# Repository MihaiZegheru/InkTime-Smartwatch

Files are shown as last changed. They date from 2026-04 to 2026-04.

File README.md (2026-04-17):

# InkTime Watch

Low-power open-source smartwatch hardware based on the **nRF52840**, designed around a **1.54” sunlight-readable e-paper display**, **BLE notifications**, **step counting**, **USB charging**, and a reliable **SWD recovery path**.

---

## Overview

InkTime is a time-first smartwatch optimized for:
- **low average power consumption**
- **high outdoor readability**
- **simple glanceable UI**
- **robust programming and recovery**
- **practical assembly for EVT/DVT prototypes**

### MVP features
- 1.54” e-paper display, **200 × 200 px**
- Partial display refresh **once per minute** for the watch face
- **BLE** notifications from a phone, with haptic alerts
- Always-on **step counting** using the accelerometer’s embedded pedometer
- **USB-C charging**
- **Tag-Connect TC2030** SWD programming/debug access

---

## Block Diagram

```text
USB-C 5V (VBUS)
   |
   v
+-------------------+
| BQ25180 Charger   |
| IN, BAT, SYS,I2C  |
+----+---------+----+
     |         |
   VBAT       VSYS
     |         |
     |         v
     |   +-------------------+
     |   | RT6160 Buck-Boost |
     |   | VIN -> 3V3        |
     |   +---------+---------+
     |             |
     v             v
+-----------+   +-------------------------------+
| MAX17048  |   | nRF52840                      |
| FuelGauge |   | BLE, USB, SPI, I2C, GPIO,SWD |
+-----+-----+   +--+---------+---------+--------+
      |            |         |         |
      |            |         |         |
      |            |         |         +--> Buttons x3
      |            |         |
      |            |         +------------> DRV2605L + ERM motor
      |            |
      |            +----------------------> BMA421 accelerometer
      |
      +-----------------------------------> Battery status / alerts

nRF52840 SPI + GPIO
        |
        v
+-------------------+
| PFET power switch |
| controls VEPD     |
+---------+---------+
          |
          v
+-------------------+
| 1.54" E-paper     |
| 200x200 display   |
+-------------------+

Tag-Connect TC2030 -> SWDIO / SWDCLK / nRESET / 3V3 / GND
```

---

## Repository Structure

```text
Hardware/
├── Schematic.sch
├── PCB.brd
└── Schematic.pdf

Manufacturing/
├── gerbers.zip
├── Bill_of_Materials.bom
└── Pick_and_Place.cpl

Mechanical/
├── InkTime-Model-Exploded.step
└── InkTime-Model.f3z

Images/
├── Exploaded.png
├── PCB.png
└── Watch.png

LICENSE
README.md
```

---

## Bill of Materials

> Main BOM items only. Passives, crystals, RF matching parts, and decoupling capacitors are listed in the exported manufacturing BOM.

| Qty | Function | Part | Ref. | JLC / LCSC | Datasheet |
|---:|---|---|---|---|---|
| 1 | MCU | nRF52840-QIAA-R | U1 | [C190794](https://jlcpcb.com/partdetail/NordicSemicon-NRF52840_QIAAR/C190794) | [Nordic Product Spec](https://docs.nordicsemi.com/bundle/ps_nrf52840/page/keyfeatures_html5.html) |
| 1 | Charger / power path | BQ25180YBGR | IC1 | [TI part page](https://www.ti.com/product/BQ25180/part-details/BQ25180YBGR) | [BQ25180 datasheet](https://www.ti.com/lit/gpn/BQ25180) |
| 1 | 3.3V regulator | RT6160AWSC | IC9 | [C7065276](https://www.lcsc.com/product-detail/C7065276.html) | [Richtek datasheet](https://www.richtek.com/Assets/product_file/RT6160A=RT6160B/DS6160AB-04.pdf) |
| 1 | Fuel gauge | MAX17048G+T10 | U3 | [C2682616](https://www.lcsc.com/product-detail/C2682616.html) | [MAX17048 datasheet](https://www.analog.com/media/en/technical-documentation/data-sheets/MAX17048-MAX17049.pdf) |
| 1 | Accelerometer | BMA421 | IC3 | [C5242966 search](https://www.jlcpcb.com/parts?searchTxt=C5242966) | [BMA421 datasheet](https://files.pine64.org/doc/datasheet/pinetime/BST-BMA421-FL000.pdf) |
| 1 | Haptic driver | DRV2605LDGSR | IC2 | [C527464](https://jlcpcb.com/partdetail/C527464) | [DRV2605L datasheet](https://www.ti.com/lit/gpn/drv2605l) |
| 1 | Vibration motor | LCM1027B3605F | M1 | [C7528806 search](https://www.jlcpcb.com/parts?searchTxt=C7528806) | [JLC search page](https://www.jlcpcb.com/parts?searchTxt=LCM1027B3605F) |
| 1 | E-paper power PFET | SI2301CDS-T1-GE3 | Q1 | [C10487](https://jlcpcb.com/partdetail/VishayIntertech-SI2301CDS_T1GE3/C10487) | [Vishay datasheet](https://www.vishay.com/docs/70209/si2301cds.pdf) |
| 1 | USB ESD protection | USBLC6-2SC6Y | D3 | [JLC search](https://www.jlcpcb.com/parts?searchTxt=USBLC6-2SC6Y) | [ST datasheet](https://www.st.com/resource/en/datasheet/usblc6-2.pdf) |
| 1 | USB-C connector | KH-TYPE-C-16P | J4 | [JLC search](https://www.jlcpcb.com/parts?searchTxt=KH-TYPE-C-16P) | [JLC search page](https://www.jlcpcb.com/parts?searchTxt=TYPE-C-16P) |
| 1 | E-paper FPC connector | 24-pin, 0.5 mm pitch | J1 | [JLC search](https://www.jlcpcb.com/parts?searchTxt=24pin%200.5mm%20FPC) | Vendor-specific |
| 1 | Debug connector footprint | Tag-Connect TC2030 | J2 | [Tag-Connect](https://www.tag-connect.com/product/tc2030-idc-nl) | [TC2030 docs](https://www.tag-connect.com/info/idc-footprint-details) |
| 3 | Buttons | SMD tactile switch | SW_UP, SW_DN, SW_ENT | [JLC search](https://www.jlcpcb.com/parts?searchTxt=EVP-AKE31A) | Vendor-specific |
| 1 | 2.4 GHz antenna | 2450AT18B100E | ANT1 | [JLC search](https://www.jlcpcb.com/parts?searchTxt=2450AT18B100E) | [Johanson datasheet](https://www.johansontechnology.com/datasheets/2450AT18B100E.pdf) |

---

## Hardware Architecture

### 1) Power tree

The board uses five main power nodes:
- **VBUS (5V):** USB input from the Type-C connector
- **VBAT:** raw LiPo battery voltage
- **VSYS:** charger system output
- **VDD_3V3:** main regulated rail from RT6160
- **VEPD:** switched display rail, enabled through a PFET

Power path:
- **USB 5V -> BQ25180 IN -> BQ25180 SYS -> RT6160 VIN -> 3.3V rail**
- **LiPo -> BQ25180 BAT**
- **LiPo -> MAX17048 BAT/VDD**

### 2) Main controller

The **nRF52840** is the main MCU and handles:
- BLE communication
- USB detection / optional USB firmware support
- SPI for the e-paper display
- I2C for low-speed peripherals
- GPIO interrupts from buttons, charger, fuel gauge, and accelerometer
- SWD programming/debug

### 3) Power-management ICs

- **BQ25180** manages USB charging and the power path.
- **RT6160** provides a stable **3.3V** rail across battery discharge.
- **MAX17048** measures battery voltage / state-of-charge directly on **VBAT**, which is more accurate than estimating charge from the 3.3V rail.

### 4) Sensors and user feedback

- **BMA421 accelerometer** is used for always-on step counting and interrupt-based wake.
- **DRV2605L** drives the vibration motor for BLE notification alerts.
- **Three buttons** provide direct user interaction and can wake the system from low-power states.

### 5) E-paper subsystem

The e-paper display is connected over **SPI** plus dedicated control lines.
A **high-side PFET** switches the display supply (**VEPD**) so the panel can be completely powered down between updates or power-cycled during recovery.

### 6) Programming and recovery

A **Tag-Connect TC2030** footprint exposes:
- **SWDIO**
- **SWDCLK**
- **nRESET**
- **3V3 reference**
- **GND**

This guarantees a reliable programming path even if the main firmware is broken.

---

## Communication Interfaces

| Interface | Connected devices |
|---|---|
| I2C | BQ25180, RT6160, MAX17048, BMA421, DRV2605L |
| SPI | E-paper display |
| USB | USB-C connector, VBUS detect, optional USB firmware path |
| SWD | TC2030 debug/programming header |
| GPIO | Buttons, interrupt lines, PFET gate, display control |

### I2C default configuration
- **SDA:** P0.06
- **SCL:** P0.07
- Pull-ups: **10 kΩ** to 3V3
- Default bus speed: **100 kHz**
- Optional validated speed: **400 kHz**

### I2C address map

| Device | Address |
|---|---:|
| BMA421 | 0x18 |
| MAX17048 | 0x36 |
| DRV2605L | 0x5A |
| BQ25180 | 0x6A |
| RT6160 | 0x75 |

---

## nRF52840 Pin Mapping

| Pin | Signal | Connected block | Reason |
|---|---|---|---|
| P0.02 | EPD_SCK | E-paper display | SPI clock |
| P0.03 | EPD_MOSI | E-paper display | SPI data out |
| P0.05 | EPD_CS | E-paper display | Dedicated chip select |
| P0.06 | I2C_SDA | Charger, regulator, fuel gauge, IMU, haptic | Shared low-speed bus |
| P0.07 | I2C_SCL | Charger, regulator, fuel gauge, IMU, haptic | Shared low-speed bus |
| P0.08 | IMU_INT1 | BMA421 | Primary wake interrupt |
| P0.12 | HAPTIC_EN | DRV2605L | Full haptic shutdown between events |
| P0.13 | BTN_UP | Button Up | Active-low user input |
| P0.14 | BTN_DN | Button Down | Active-low user input |
| P0.15 | EPD_DC | E-paper display | Data / command select |
| P0.16 | EPD_RST | E-paper display | Hardware reset |
| P0.17 | EPD_BUSY | E-paper display | Busy feedback |
| P1.00 | BTN_ENT | Enter / Esc button | Active-low user input |
| P1.01 | EPD_PWR_GATE | PFET gate | Enables VEPD power gating |
| P1.08 | IMU_INT2 | BMA421 | Secondary interrupt / debug |
| SWDIO | SWDIO | TC2030 | Programming / debug |
| SWDCLK | SWDCLK | TC2030 | Programming / debug |
| nRESET | RESET | TC2030 | Reliable recovery |
| USBDP | USB_D+ | USB-C / ESD | Native USB |
| USBDM | USB_D- | USB-C / ESD | Native USB |
| VBUS | USB_VBUS_DET | USB-C | USB attach detection |
| XC1/XC2 | 32 MHz crystal | X1 | Main radio/system clock |
| XL1/XL2 | 32.768 kHz crystal | X2 | RTC / low-power timekeeping |
| ANT | RF | Matching network + antenna | BLE antenna feed |

---

## Power Budget Notes

The product is designed around **average current reduction**, not just low peak current.

Main strategies:
- e-paper for near-zero static display power
- partial refresh once per minute instead of continuous refresh
- accelerometer used in interrupt/pedometer mode
- haptic driver disabled when idle
- optional BLE duty cycling instead of permanent active connection
- optional **VEPD** power gating through the PFET

### Validation measurements recommended during EVT
- deep-sleep current
- current during minute-tick partial refresh
- current during BLE notification event
- current during haptic event
- 24-hour average current for a realistic user profile

---

## PCB Design Notes

- **4-layer PCB recommended** for RF behavior and power integrity
- Main components placed on the **TOP** layer
- **Power traces:** minimum **0.3 mm** where possible
- **Signal traces:** minimum **0.15 mm**
- No right-angle routing
- Local **100 nF** decoupling placed close to power pins
- Ground stitching used between planes, especially near RF
- **No copper, no routing, and no ground plane under the antenna**
- Charger/regulator kept away from antenna and RF matching network
- Accelerometer placed away from the vibration motor to reduce false motion coupling
- USB differential pair routed tightly with ESD protection close to the connector
- Test pads should be clearly labeled in silkscreen

---

## Mechanical Notes

Mechanical stack:
- top lens
- e-paper module
- PCB
- battery
- vibration motor
- back cover

Design goals:
- protect the e-paper panel from bending
- align the physical enclosure buttons with PCB switches
- keep the battery away from the antenna keepout
- mechanically couple the motor to the case for better haptic transfer
- provide access to USB-C for charging and bring-up

---

## Bring-Up Checklist

1. Verify TC2030 SWD wiring.
2. Flash basic test firmware.
3. Confirm stable 3.3V rail.
4. Measure baseline sleep current.
5. Run I2C scan and detect all devices.
6. Read MAX17048 battery data.
7. Verify BQ25180 charger status.
8. Validate RT6160 output across battery range.
9. Power up the e-paper rail and test refresh.
10. Run DRV2605L motor test.
11. Validate button interrupts and debounce.
12. Validate BMA421 wake/step interrupts.

---

## Design Decisions

- **nRF52840** chosen for BLE + USB + mature tooling
- **E-paper** chosen for sunlight readability and very low average power
- **RT6160 buck-boost** used to keep the 3.3V rail stable across battery discharge
- **MAX17048** added for direct battery monitoring
- **PFET display gating** added for leakage reduction and display recovery
- **TC2030 SWD** kept mandatory for reliable bring-up and recovery

---

## Manufacturing Outputs

The final repository should include:
- native schematic and PCB files
- schematic PDF
- Gerber archive
- BOM export
- pick-and-place / CPL export
- full 3D assembly in **STEP** and **Fusion360** formats
- rendered images of the PCB and full assembly

---

## Images

```md
![Schematic](Images/schematic.png)
![PCB 2D](Images/pcb_2d.png)
![PCB 3D](Images/pcb_3d.png)
![Exploded View](Images/exploded_view.png)
```

---

## License

Recommended: **Apache-2.0** or **MIT**.

---

## Submission Notes

Before submission, make sure the final repo contains:
- exact manufacturing exports
- final board screenshots/renders
- the 3D assembly
- the review issues raised during DVT
- any justified design-rule exceptions documented in GitHub issues or commit notes

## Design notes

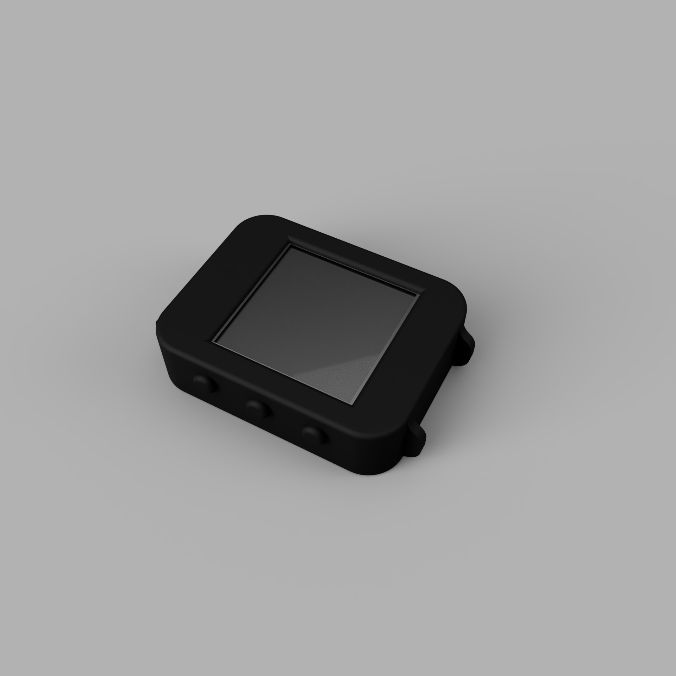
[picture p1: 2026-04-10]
Images/Watch.png

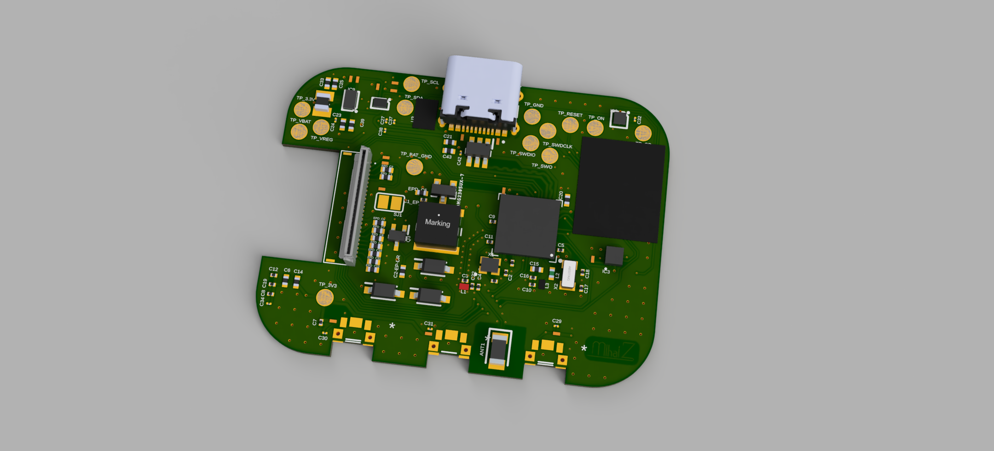
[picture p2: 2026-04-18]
Images/PCB.png

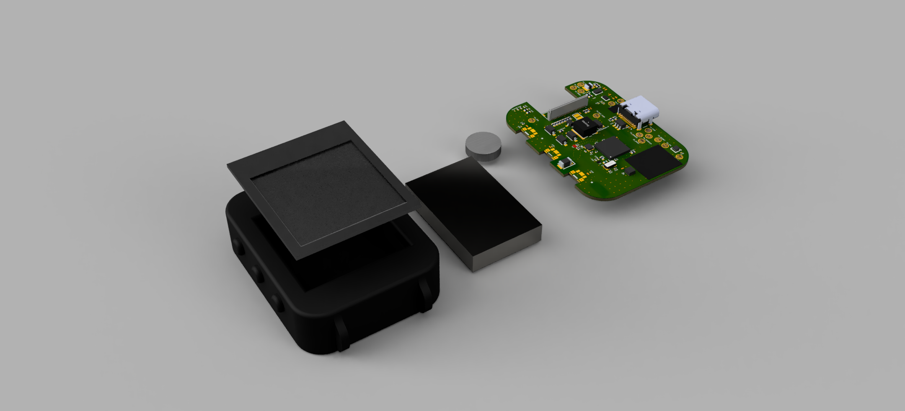
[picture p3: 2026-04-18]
Images/Exploded.png

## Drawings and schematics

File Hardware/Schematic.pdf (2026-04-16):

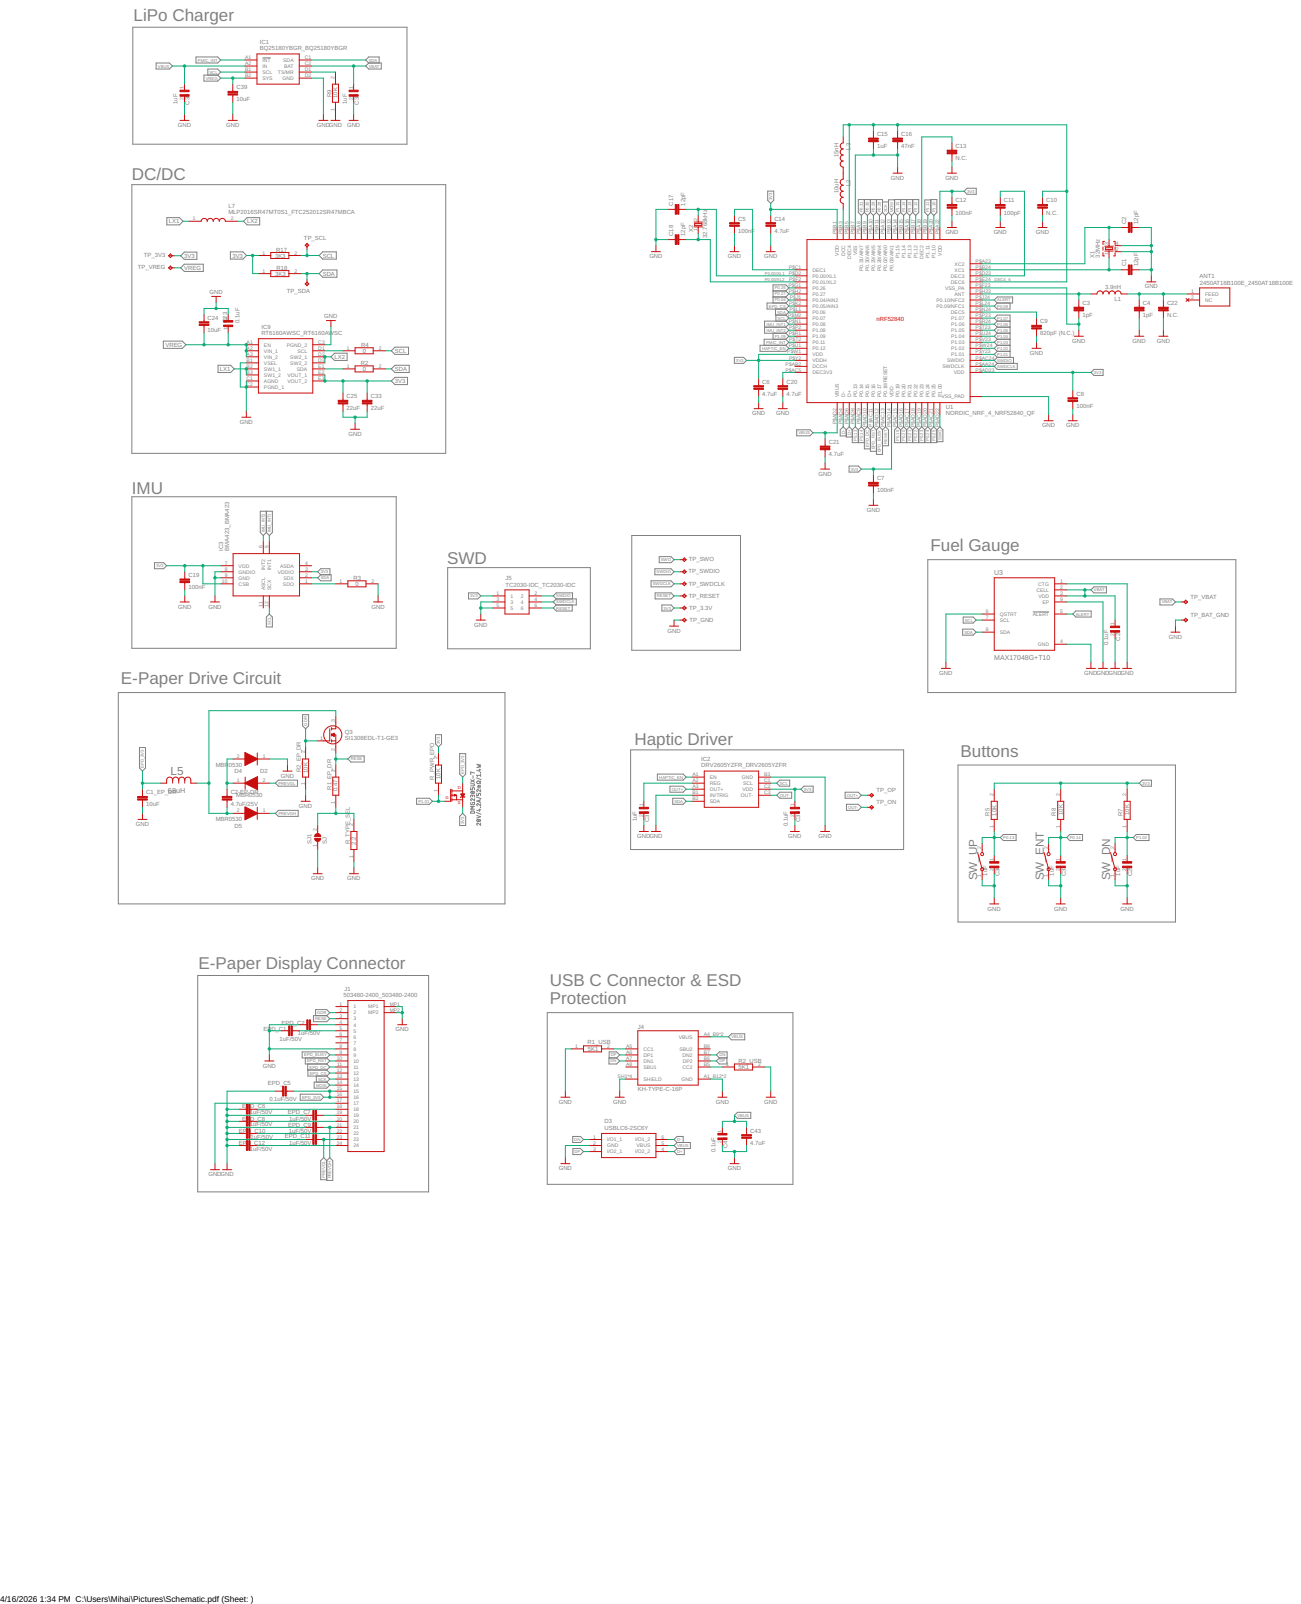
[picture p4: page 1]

EPD_C6 | 18
1uF/50V EPD_C7 | 19
EPD_C8 | 1uF/50V | 20
1uF/50V EPD_C9 | 21
EPD_C10 | 1uF/50V | | 22

4/16/2026 1:34 PM C:\Users\Mihai\Pictures\Schematic.pdf (Sheet: )

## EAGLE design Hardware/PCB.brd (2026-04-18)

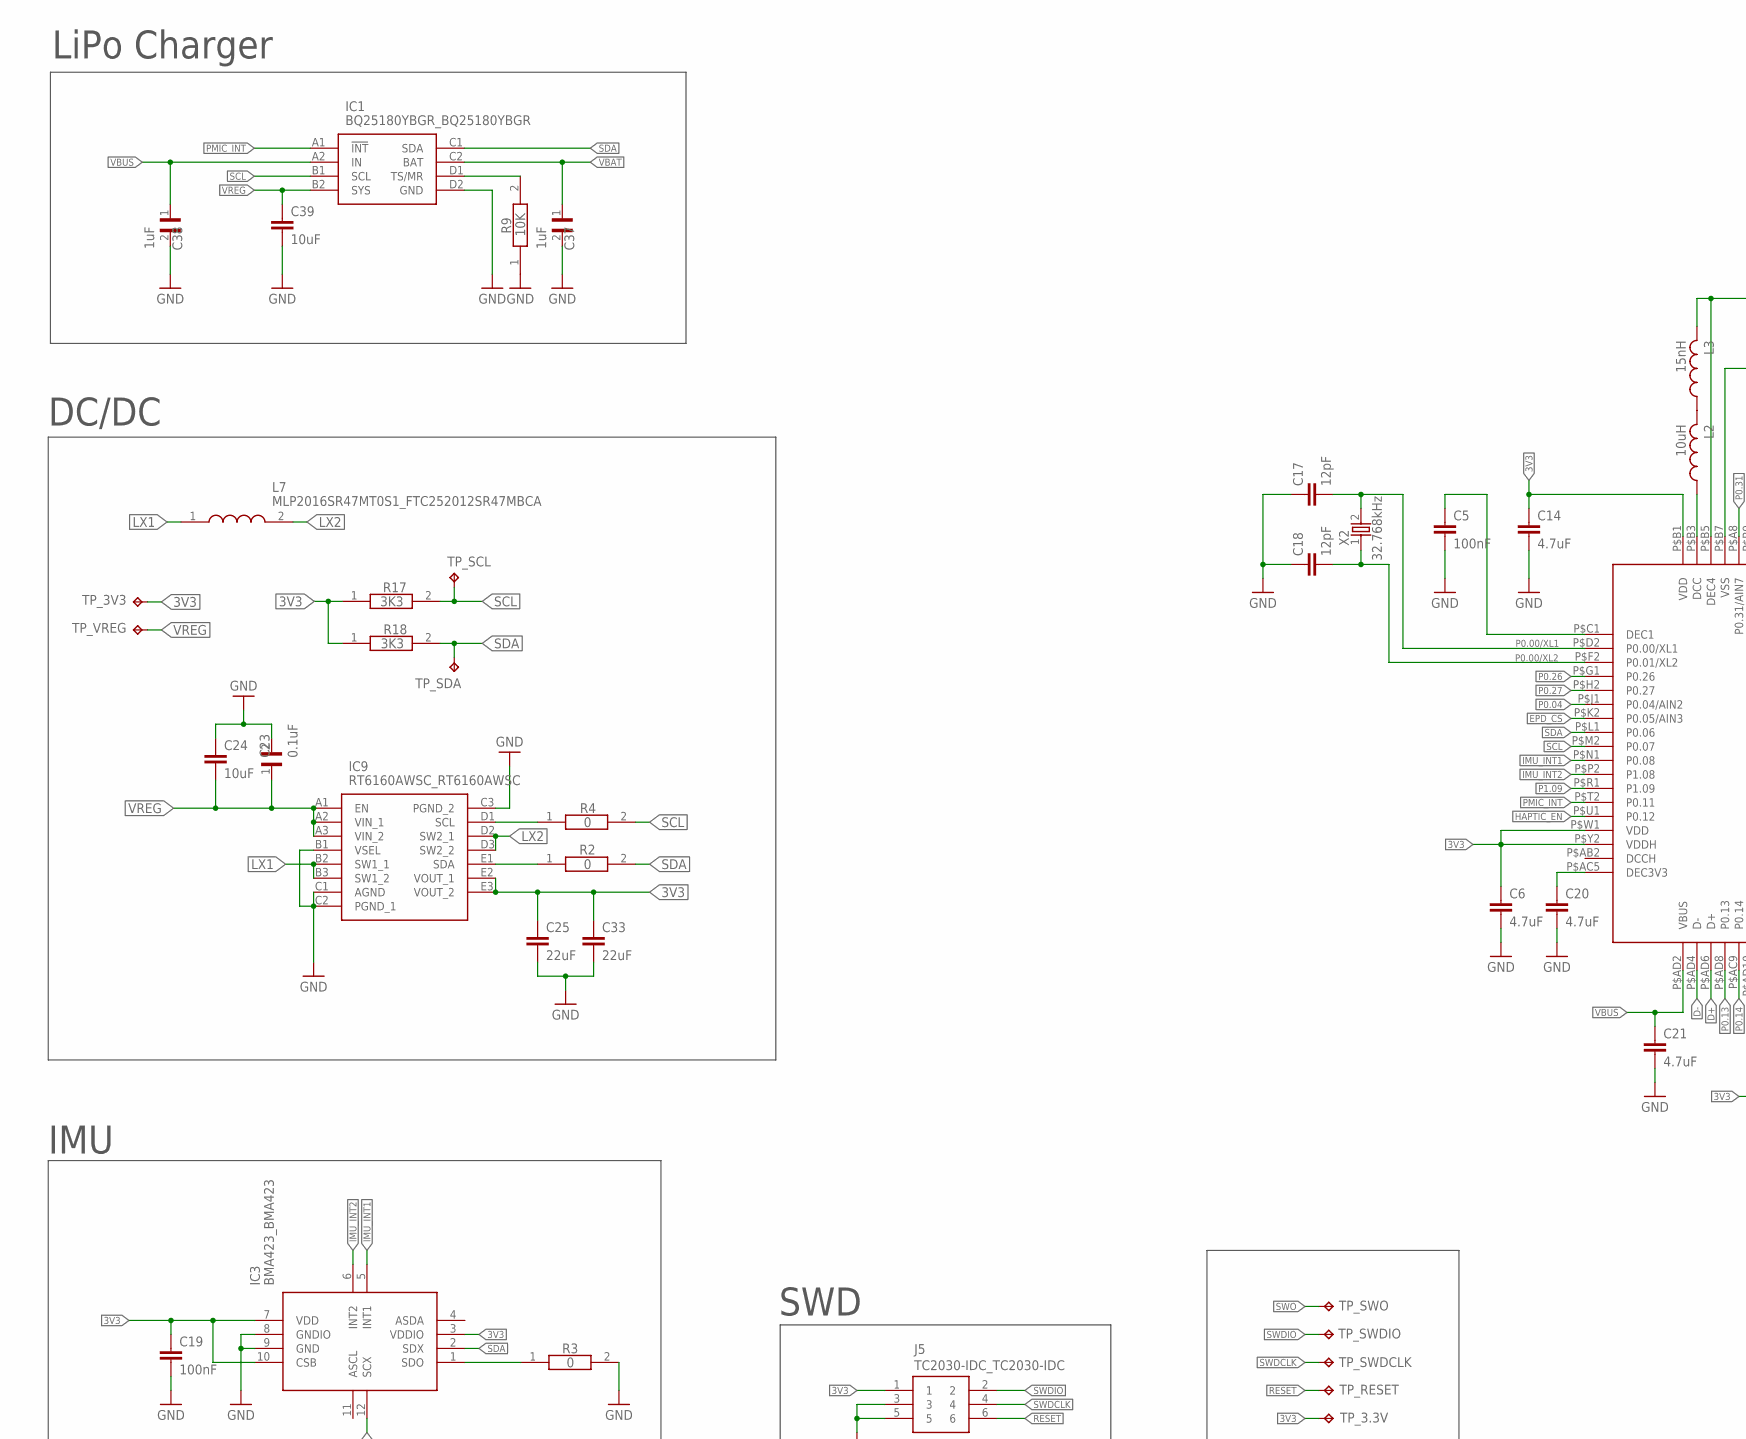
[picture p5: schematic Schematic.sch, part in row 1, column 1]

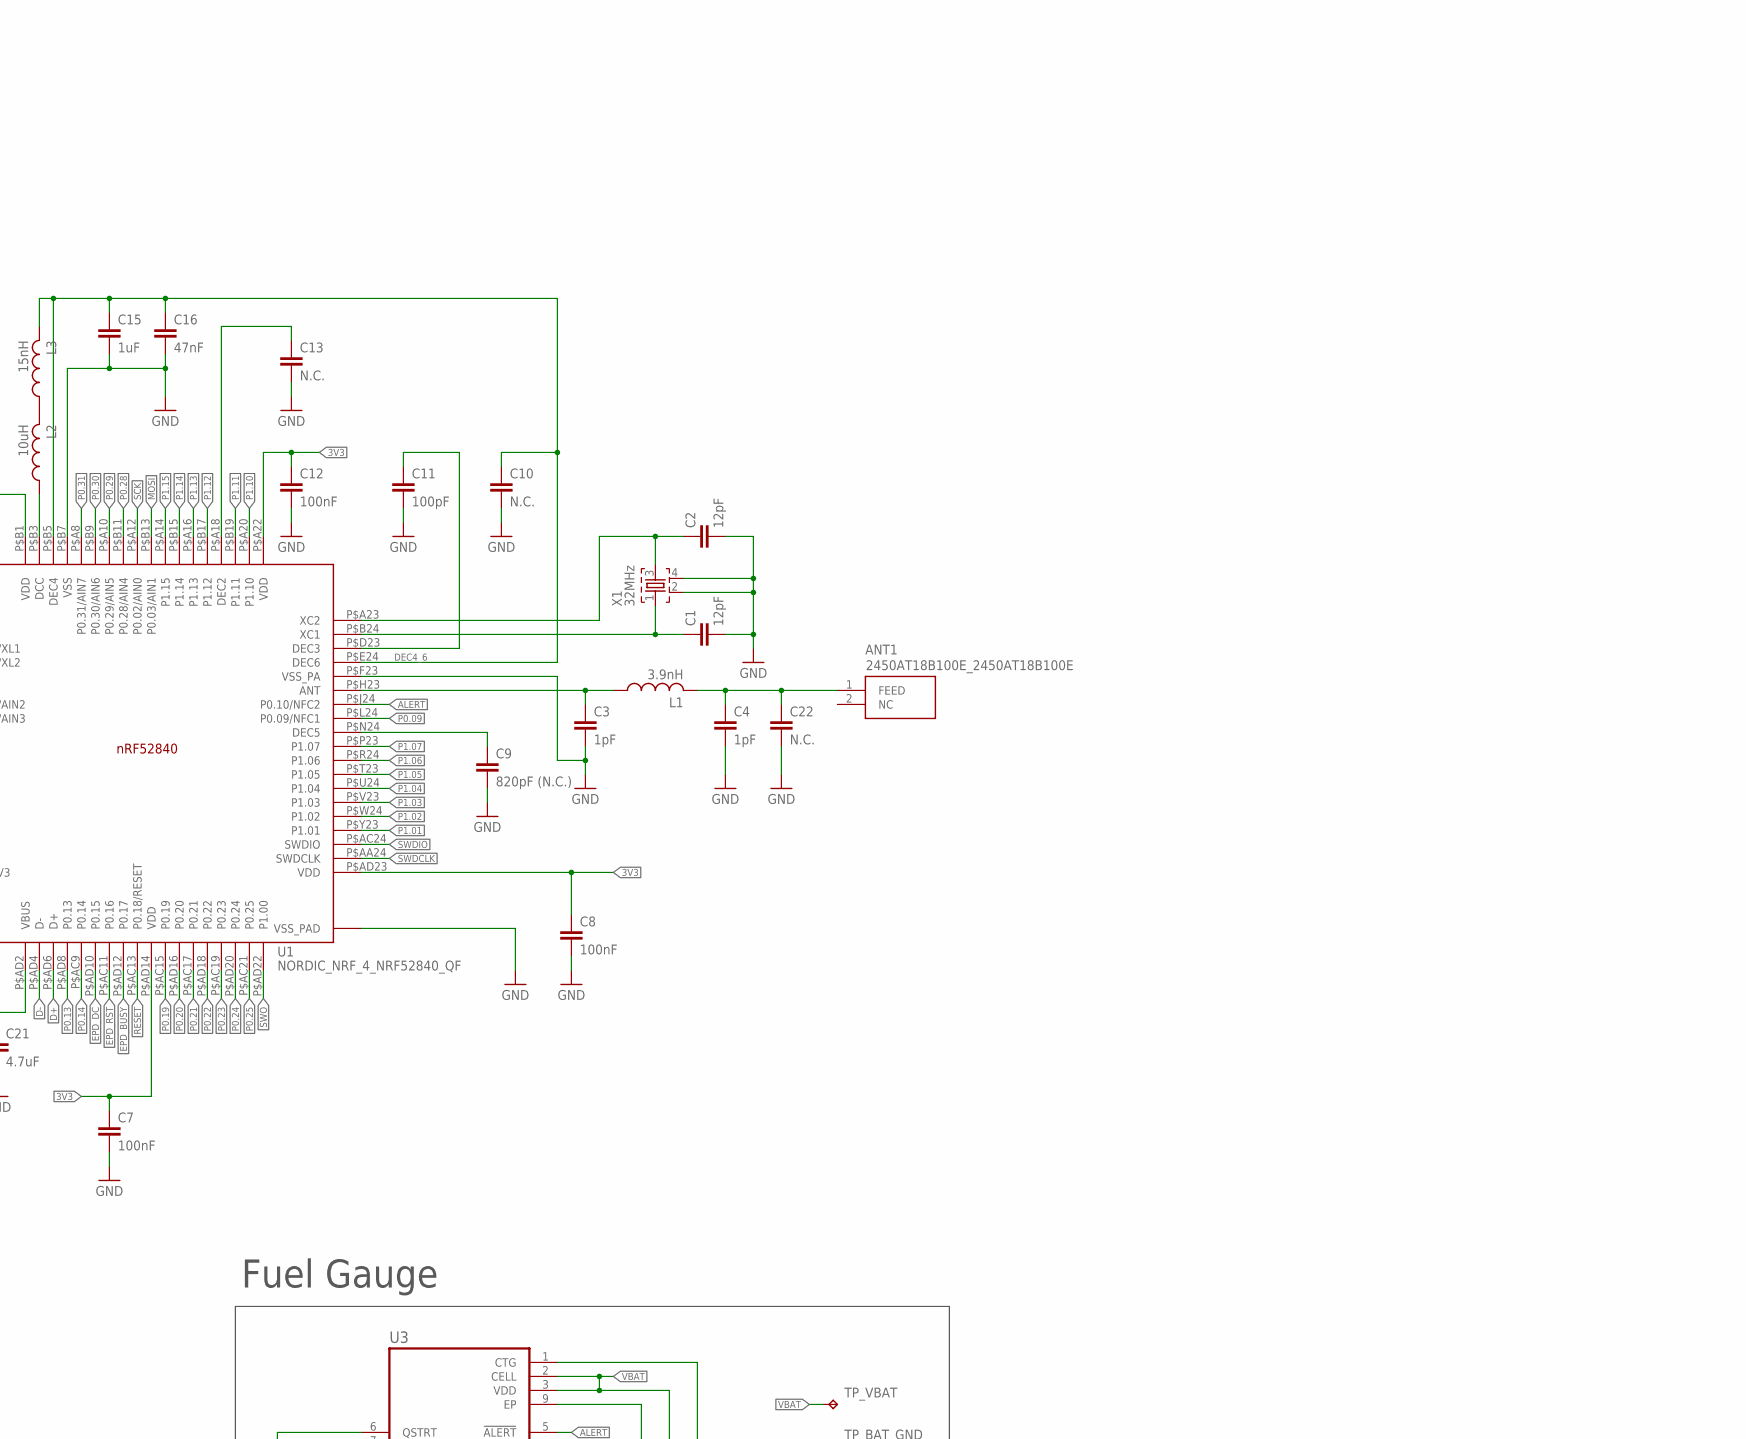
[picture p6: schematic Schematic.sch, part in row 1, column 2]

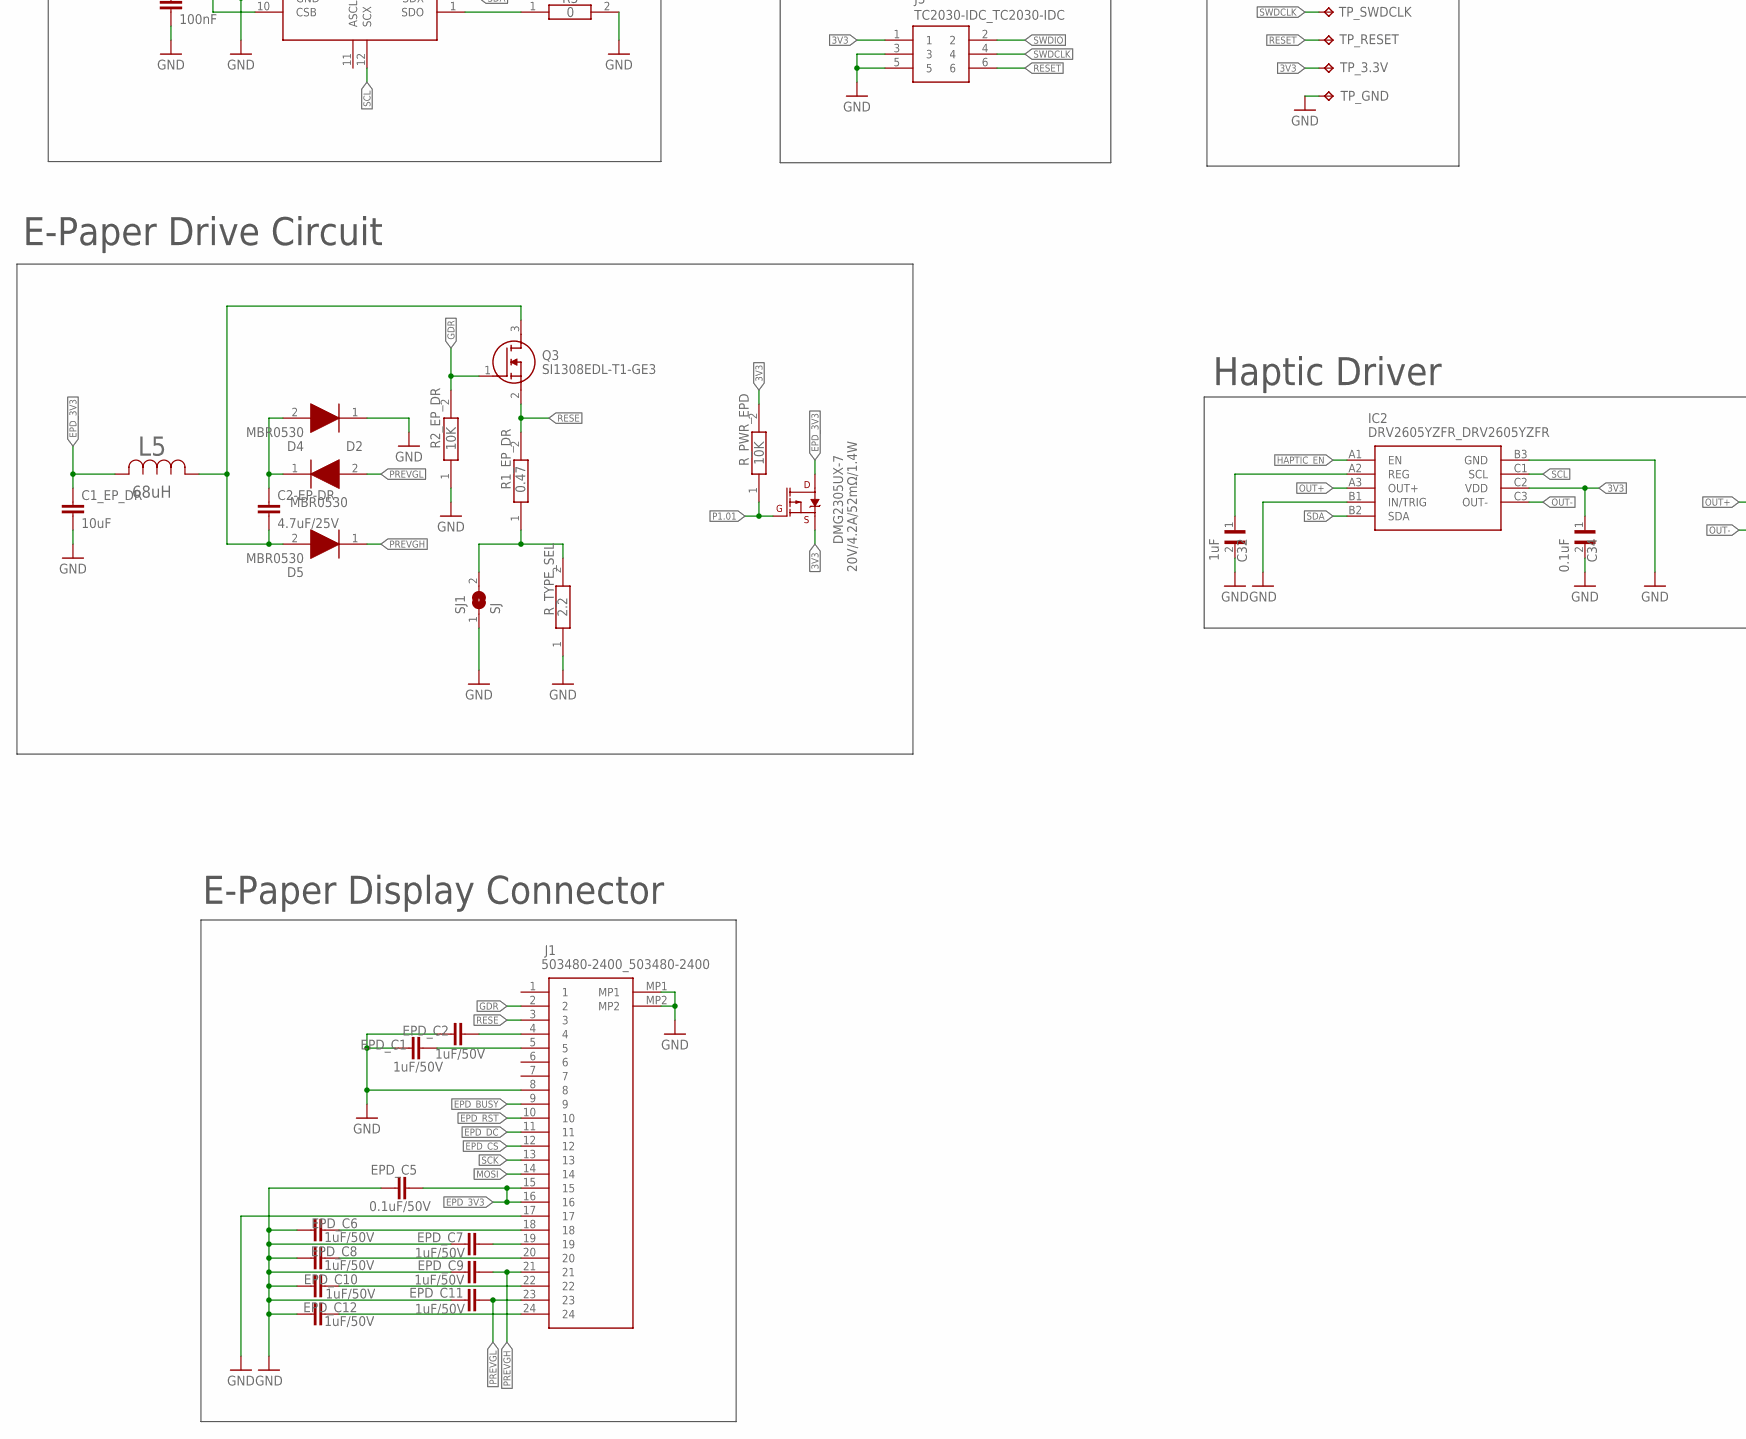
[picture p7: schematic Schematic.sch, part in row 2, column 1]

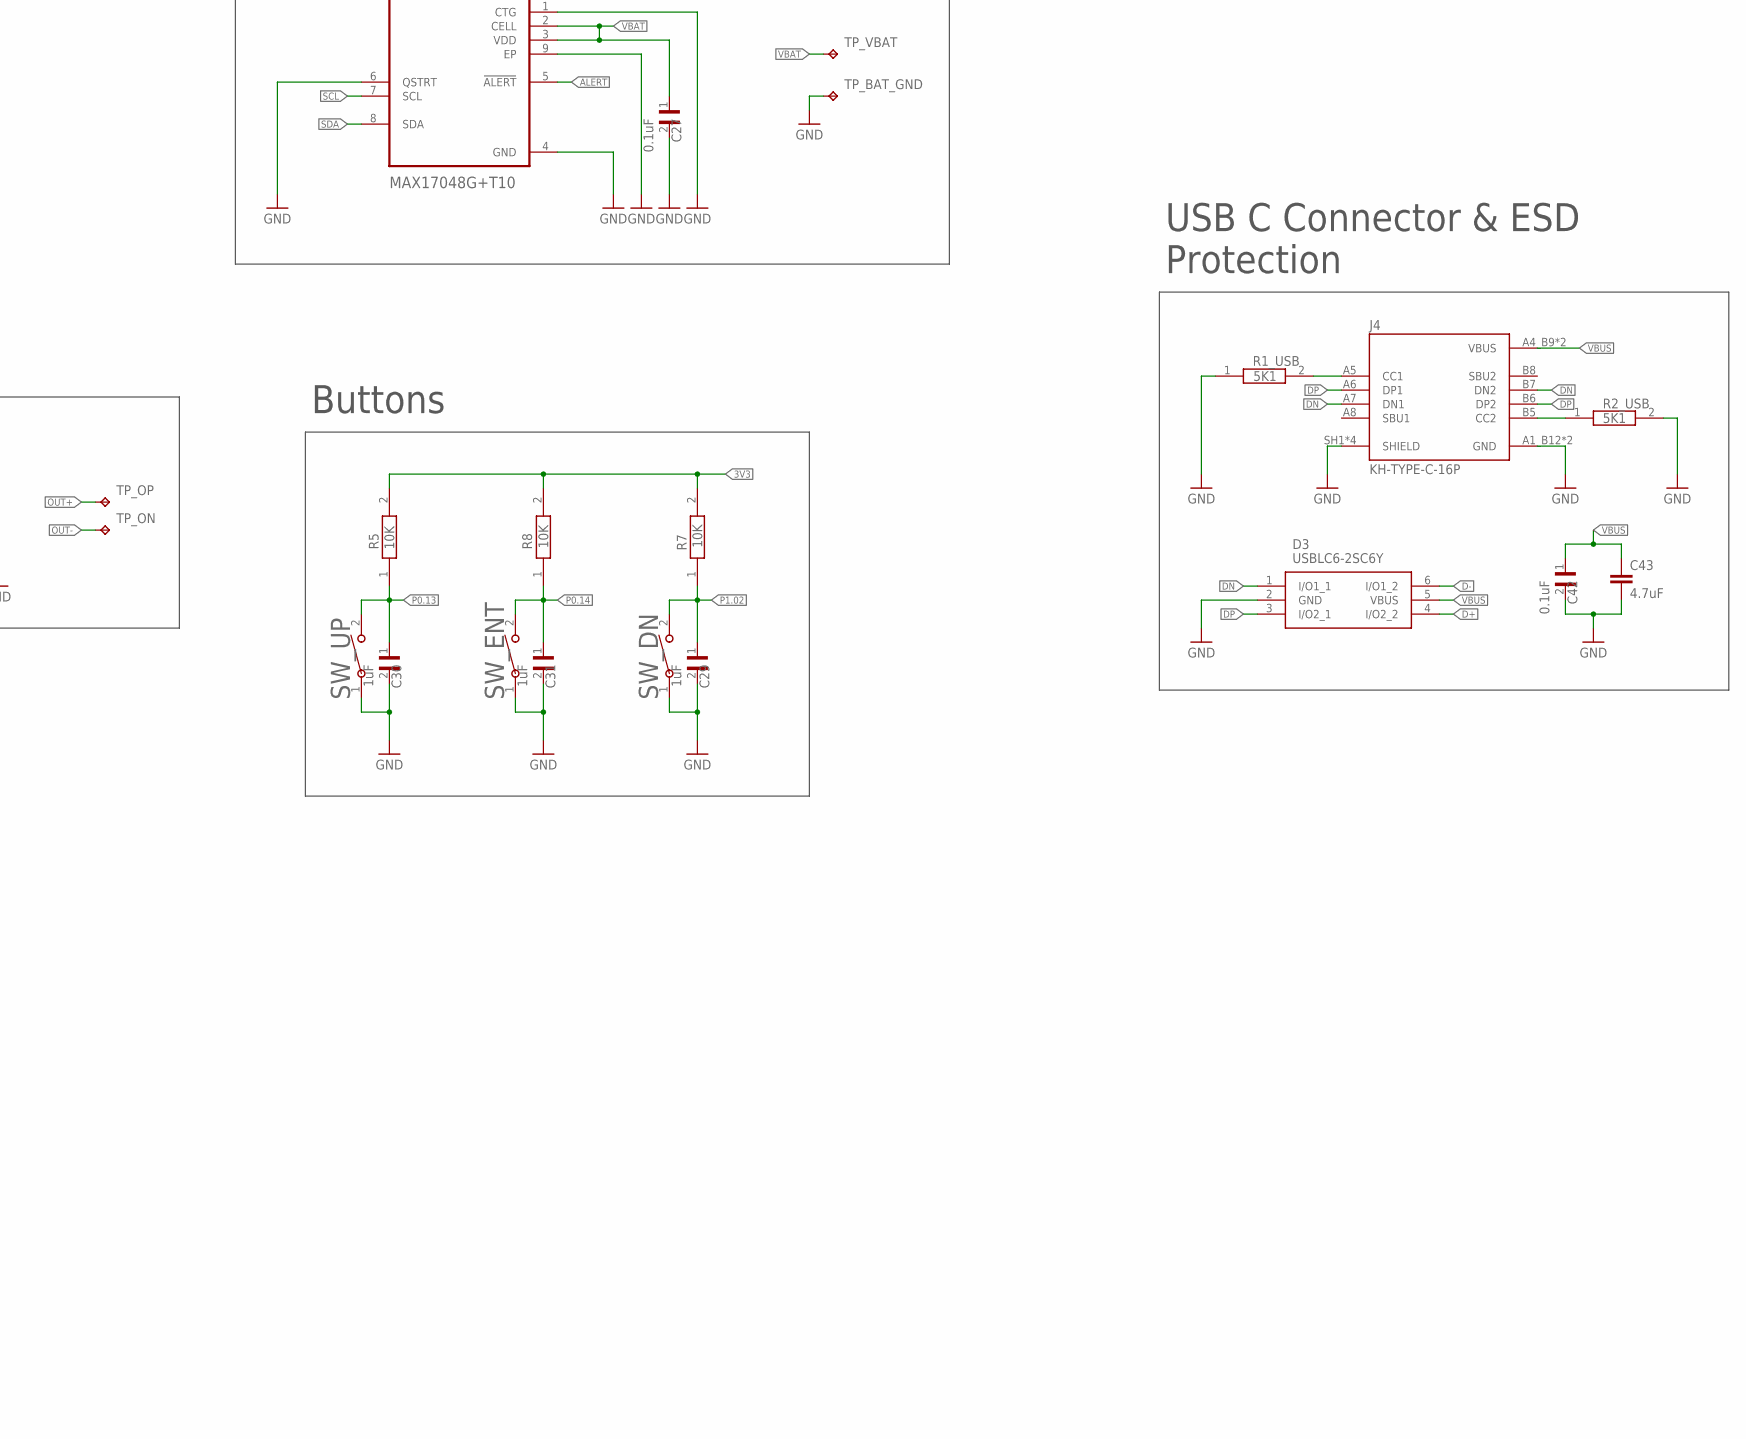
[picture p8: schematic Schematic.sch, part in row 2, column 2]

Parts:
ANT1: 2450AT18B100E_2450AT18B100E; 2450AT18B100E_ANTC3216X140N
C1, C2, C17, C18: 12pF; NORDIC_NRF_3_RESC0201_L
C1_EP_DR, C24, C39: 10uF; NORDIC_NRF_3_RESC0402_L
C2-EP-DR: 4.7uF/25V; NORDIC_NRF_3_RESC0402_L
C3, C4: 1pF; NORDIC_NRF_3_RESC0201_L
C5, C7, C8, C12, C19: 100nF; NORDIC_NRF_3_RESC0201_L
C6, C14, C20, C21, C43: 4.7uF; NORDIC_NRF_3_RESC0402_L
C9: 820pF (N.C.); NORDIC_NRF_3_RESC0201_L
C10, C13, C22: N.C.; NORDIC_NRF_3_RESC0201_L
C11: 100pF; NORDIC_NRF_3_RESC0201_L
C15: 1uF; NORDIC_NRF_3_RESC0402_L
C16: 47nF; NORDIC_NRF_3_RESC0201_L
C23, C27, C34, C42: 0.1uF; GRM011R60J152KE01L_2_CAPC0201X13N
C25, C33: 22uF; NORDIC_NRF_3_RESC0402_L
C29, C30, C31, C32, C37, C38: 1uF; GRM011R60J152KE01L_2_CAPC0201X13N
D2, D4, D5: MBR0530; ESP32_C6_LIBRARY_5_SOD3716X135N
D3: USBLC6-2SC6Y; ESP32_C6_LIBRARY_3_SOT95P280X145-6N
DMG2305UX-7: 20V/4.2A/52mΩ/1.4W; ESP32_C6_LIBRARY_4_ESP32_C6_LIBRARY_4_ESP32_C6_LIBRARY_4_ES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
EPD_C1, EPD_C2, EPD_C6, EPD_C7, EPD_C8, EPD_C9, EPD_C10, EPD_C11, EPD_C12: 1uF/50V; NORDIC_NRF_3_RESC0402_L
EPD_C5: 0.1uF/50V; NORDIC_NRF_3_RESC0201_L
IC1: BQ25180YBGR_BQ25180YBGR; BQ25180YBGR_BGA8C40P2X4_100X155X50
IC2: DRV2605YZFR_DRV2605YZFR; DRV2605YZFR_BGA9C50P3X3_144X144X62
IC3: BMA423_BMA423
IC9: RT6160AWSC_RT6160AWSC; RT6160AWSC_BGA15C40P3X5_140X230X60
J1: 503480-2400_503480-2400; 503480-2400_5034802400
J4: KH-TYPE-C-16P; KH-TYPE-C-16P_KINGHELM_KH-TYPE-C-16P
J5: TC2030-IDC_TC2030-IDC; TC2030-IDC_TC2030IDC
L1: 3.9nH; NORDIC_NRF_2_RESC0201_L
L2: 10uH; NORDIC_NRF_2_RESC0402_L
L3: 15nH; NORDIC_NRF_2_RESC0201_L
L5: 68uH; ESP32_C6_LIBRARY_2_IND_4828-WE-TPC_WRE
L7: MLP2016SR47MT0S1_FTC252012SR47MBCA; MLP2016SR47MT0S1_INDC2016X100N
Q3: SI1308EDL-T1-GE3; ESP32_C6_LIBRARY_6_SOT65P210X110-3N
R1_EP_DR: 0.47; CPF0201D7K68C1_0201
R1_USB, R2_USB: 5K1; CPF0201D7K68C1_0201
R2, R3, R4: 0; CPF0201D7K68C1_0201
R2_EP_DR, R5, R7, R8, R9: 10K; CPF0201D7K68C1_0201
R17, R18: 3K3; CPF0201D7K68C1_0201
R_PWR_EPD: 10K; CPF0201D7K68C1_0201
R_TYPE_SEL: 2.2; CPF0201D7K68C1_0201
SJ1: SJ; ESP32_C6_LIBRARY_7_JUMPER_SJ
SW_DN: 2025-10-22_07-23-44_LIBRARY_EVP-AKE31ASW_EVP-AKE3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; 2025-10-22_07-23-44_LIBRARY_SW_EVP-AKE31A_PAN
SW_ENT: 2025-10-22_07-23-44_LIBRARY_EVP-AKE31ASW_EVP-AKE3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; 2025-10-22_07-23-44_LIBRARY_SW_EVP-AKE31A_PAN
SW_UP: 2025-10-22_07-23-44_LIBRARY_EVP-AKE31ASW_EVP-AKE3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; 2025-10-22_07-23-44_LIBRARY_SW_EVP-AKE31A_PAN
TP_3.3V, TP_3V3: HECTOR_WATCH_1_TPTP20R; HECTOR_WATCH_1_TP20R
TP_BAT_GND: HECTOR_WATCH_1_TPTP20R; HECTOR_WATCH_1_TP20R
TP_GND: HECTOR_WATCH_1_TPTP20R; HECTOR_WATCH_1_TP20R
TP_ON: HECTOR_WATCH_1_TPTP20R; HECTOR_WATCH_1_TP20R
TP_OP: HECTOR_WATCH_1_TPTP20R; HECTOR_WATCH_1_TP20R
TP_RESET: HECTOR_WATCH_1_TPTP20R; HECTOR_WATCH_1_TP20R
TP_SCL: HECTOR_WATCH_1_TPTP20R; HECTOR_WATCH_1_TP20R
TP_SDA: HECTOR_WATCH_1_TPTP20R; HECTOR_WATCH_1_TP20R
TP_SWDCLK: HECTOR_WATCH_1_TPTP20R; HECTOR_WATCH_1_TP20R
TP_SWDIO: HECTOR_WATCH_1_TPTP20R; HECTOR_WATCH_1_TP20R
TP_SWO: HECTOR_WATCH_1_TPTP20R; HECTOR_WATCH_1_TP20R
TP_VBAT: HECTOR_WATCH_1_TPTP20R; HECTOR_WATCH_1_TP20R
TP_VREG: HECTOR_WATCH_1_TPTP20R; HECTOR_WATCH_1_TP20R
U1: NORDIC_NRF_4_NRF52840_QF; NORDIC_NRF_4_AQFN50P700X700X85_HS-74N
U3: MAX17048G+T10; ESP32_C6_LIBRARY_SON50P200X200X80-9N
X1: 32MHz; NORDIC_NRF_BT-XTAL_2016_N
X2: 32.768kHz; NORDIC_NRF_1_XTAL_3215_N

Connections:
3V3: C6.1, C7.1, C8.1, C12.1, C14.1, C19.1, C25.1, C33.1, C34.1, DMG2305UX-7.2 (S), IC2.C2 (VDD), IC3.3 (VDDIO), IC3.7 (VDD), IC3.10 (CSB), IC9.E2 (VOUT_1), IC9.E3 (VOUT_2), J5.1, R5.2, R7.2, R8.2, R17.1, R18.1, R_PWR_EPD.2, TP_3.3V.TP, TP_3V3.TP, U1.P$A22 (VDD), U1.P$AD14 (VDD), U1.P$AD23 (VDD), U1.P$B1 (VDD), U1.P$W1 (VDD), U1.P$Y2 (VDDH)
ALERT: U1.P$J24 (P0.10/NFC2), U3.5 (!ALERT)
D+: D3.4 (I/O2_2), U1.P$AD6 (D+)
D-: D3.6 (I/O1_2), U1.P$AD4 (D-)
DEC4_6: C10.1, C15.1, C16.1, L3.2, U1.P$B5 (DEC4), U1.P$E24 (DEC6)
DN: D3.1 (I/O1_1), J4.A7 (DN1), J4.B7 (DN2)
DP: D3.3 (I/O2_1), J4.A6 (DP1), J4.B6 (DP2)
EPD_3V3: C1_EP_DR.1, DMG2305UX-7.3 (D), EPD_C5.2, J1.15, J1.16, L5.2
EPD_BUSY: J1.9, U1.P$AD12 (P0.17)
EPD_CS: J1.12, U1.P$K2 (P0.05/AIN3)
EPD_DC: J1.11, U1.P$AD10 (P0.15)
EPD_RST: J1.10, U1.P$AC11 (P0.16)
GDR: J1.2, Q3.1 (G), R2_EP_DR.2
GND: C1.2, C1_EP_DR.2, C2.2, C3.2, C4.2, C5.2, C6.2, C7.2, C8.2, C9.2, C10.2, C11.2, C12.2, C13.2, C14.2, C15.2, C16.2, C17.1, C18.1, C19.2, C20.2, C21.2, C22.2, C23.2, C24.1, C25.2, C27.2, C29.2, C30.2, C31.2, C32.2, C33.2, C34.2, C37.2, C38.2, C39.2, C42.2, C43.2, D3.2 (GND), D4.1 (K), EPD_C1.1, EPD_C2.1, EPD_C5.1, EPD_C6.1, EPD_C7.1, EPD_C8.1, EPD_C9.1, EPD_C10.1, EPD_C11.1, EPD_C12.1, IC1.D2 (GND), IC2.B1 (IN/TRIG), IC2.B3 (GND), IC3.8 (GNDIO), IC3.9 (GND), IC9.B1 (VSEL), IC9.C1 (AGND), IC9.C2 (PGND_1), IC9.C3 (PGND_2), J1.8, J1.17, J1.MP1, J1.MP2, J4.A1_B12 (GND), J4.A12_B1 (GND), J4.SH1 (SHIELD), J4.SH2 (SHIELD), J4.SH3 (SHIELD), J4.SH4 (SHIELD), J5.3, J5.5, R1_USB.1, R2_EP_DR.1, R2_USB.2, R3.2, R9.1, R_TYPE_SEL.1, SJ1.1, SW_DN.1, SW_ENT.1, SW_UP.1, TP_BAT_GND.TP, TP_GND.TP, U1.P$74 (VSS_PAD), U1.P$75 (VSS_PAD), U1.P$76 (VSS_PAD), U1.P$77 (VSS_PAD), U1.P$78 (VSS_PAD), U1.P$79 (VSS_PAD), U1.P$80 (VSS_PAD), U1.P$81 (VSS_PAD), U1.P$82 (VSS_PAD), U1.P$83 (VSS_PAD), U1.P$84 (VSS_PAD), U1.P$85 (VSS_PAD), U1.P$86 (VSS_PAD), U1.P$87 (VSS_PAD), U1.P$88 (VSS_PAD), U1.P$89 (VSS_PAD), U1.P$90 (VSS_PAD), U1.P$B7 (VSS), U1.P$F23 (VSS_PA), U3.1 (CTG), U3.4 (GND), U3.6 (QSTRT), U3.9 (EP), X1.2, X1.4
HAPTIC_EN: IC2.A1 (EN), U1.P$U1 (P0.12)
IMU_INT1: IC3.5 (INT1), U1.P$N1 (P0.08)
IMU_INT2: IC3.6 (INT2), U1.P$P2 (P1.08)
LX1: IC9.B2 (SW1_1), IC9.B3 (SW1_2), L7.1
LX2: IC9.D2 (SW2_1), IC9.D3 (SW2_2), L7.2
MOSI: J1.14, U1.P$B13 (P0.03/AIN1)
unnamed: L2.2, L3.1
unnamed: IC9.D1 (SCL), R4.1
unnamed: C32.1, IC2.A2 (REG)
unnamed: IC9.E1 (SDA), R2.1
unnamed: IC3.1 (SDO), R3.1
unnamed: C5.1, U1.P$C1 (DEC1)
unnamed: IC1.D1 (TS/MR), R9.2
unnamed: C2-EP-DR.1, D2.1 (K), D4.2 (A)
unnamed: EPD_C6.2, J1.18
unnamed: R1_EP_DR.1, R_TYPE_SEL.2, SJ1.2
unnamed: J4.A5 (CC1), R1_USB.2
unnamed: EPD_C2.2, J1.4
unnamed: EPD_C1.2, J1.5
unnamed: J4.B5 (CC2), R2_USB.1
unnamed: EPD_C7.2, J1.19
unnamed: C2-EP-DR.2, D5.2 (A), L5.1, Q3.3 (D)
unnamed: C20.1, U1.P$AC5 (DEC3V3)
unnamed: EPD_C8.2, J1.20
unnamed: EPD_C12.2, J1.24
unnamed: EPD_C10.2, J1.22
unnamed: L2.1, U1.P$B3 (DCC)
unnamed: C13.1, U1.P$A18 (DEC2)
unnamed: C9.1, U1.P$N24 (DEC5)
unnamed: C11.1, U1.P$D23 (DEC3)
unnamed: C2.1, U1.P$A23 (XC2), X1.3
unnamed: C1.1, U1.P$B24 (XC1), X1.1
unnamed: C3.1, L1.1, U1.P$H23 (ANT)
unnamed: ANT1.1 (FEED), C4.1, C22.1, L1.2
OUT+: IC2.A3 (OUT+), TP_OP.TP
OUT-: IC2.C3 (OUT-), TP_ON.TP
P0.00/XL1: C17.2, U1.P$D2 (P0.00/XL1), X2.2
P0.00/XL2: C18.2, U1.P$F2 (P0.01/XL2), X2.1
P0.04: U1.P$J1 (P0.04/AIN2)
P0.09: U1.P$L24 (P0.09/NFC1)
P0.13: C30.1, R5.1, SW_UP.2, U1.P$AD8 (P0.13)
P0.14: C31.1, R8.1, SW_ENT.2, U1.P$AC9 (P0.14)
P0.19: U1.P$AC15 (P0.19)
P0.20: U1.P$AD16 (P0.20)
P0.21: U1.P$AC17 (P0.21)
P0.22: U1.P$AD18 (P0.22)
P0.23: U1.P$AC19 (P0.23)
P0.24: U1.P$AD20 (P0.24)
P0.25: U1.P$AC21 (P0.25)
P0.26: U1.P$G1 (P0.26)
P0.27: U1.P$H2 (P0.27)
P0.28: U1.P$B11 (P0.28/AIN4)
P0.29: U1.P$A10 (P0.29/AIN5)
P0.30: U1.P$B9 (P0.30/AIN6)
P0.31: U1.P$A8 (P0.31/AIN7)
P1.01: DMG2305UX-7.1 (G), R_PWR_EPD.1, U1.P$Y23 (P1.01)
P1.02: C29.1, R7.1, SW_DN.2, U1.P$W24 (P1.02)
P1.03: U1.P$V23 (P1.03)
P1.04: U1.P$U24 (P1.04)
P1.05: U1.P$T23 (P1.05)
P1.06: U1.P$R24 (P1.06)
P1.07: U1.P$P23 (P1.07)
P1.09: U1.P$R1 (P1.09)
P1.10: U1.P$A20 (P1.10)
P1.11: U1.P$B19 (P1.11)
P1.12: U1.P$B17 (P1.12)
P1.13: U1.P$A16 (P1.13)
P1.14: U1.P$B15 (P1.14)
P1.15: U1.P$A14 (P1.15)
PMIC_INT: IC1.A1 (!INT), U1.P$T2 (P0.11)
PREVGH: D5.1 (K), EPD_C9.2, J1.21
PREVGL: D2.2 (A), EPD_C11.2, J1.23
RESE: J1.3, Q3.2 (S), R1_EP_DR.2
RESET: J5.6, TP_RESET.TP, U1.P$AC13 (P0.18/RESET)
SCK: J1.13, U1.P$A12 (P0.02/AIN0)
SCL: IC1.B1 (SCL), IC2.C1 (SCL), IC3.12 (SCX), R4.2, R17.2, TP_SCL.TP, U1.P$M2 (P0.07), U3.7 (SCL)
SDA: IC1.C1 (SDA), IC2.B2 (SDA), IC3.2 (SDX), R2.2, R18.2, TP_SDA.TP, U1.P$L1 (P0.06), U3.8 (SDA)
SWDCLK: J5.4, TP_SWDCLK.TP, U1.P$AA24 (SWDCLK)
SWDIO: J5.2, TP_SWDIO.TP, U1.P$AC24 (SWDIO)
SWO: TP_SWO.TP, U1.P$AD22 (P1.00)
VBAT: C27.1, C37.1, IC1.C2 (BAT), TP_VBAT.TP, U3.2 (CELL), U3.3 (VDD)
VBUS: C21.1, C38.1, C42.1, C43.1, D3.5 (VBUS), IC1.A2 (IN), J4.A4_B9 (VBUS), J4.A9_B4 (VBUS), U1.P$AD2 (VBUS)
VREG: C23.1, C24.2, C39.1, IC1.B2 (SYS), IC9.A1 (EN), IC9.A2 (VIN_1), IC9.A3 (VIN_2), TP_VREG.TP

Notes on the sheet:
DC/DC
LiPo Charger
IMU
SWD
E-Paper Drive Circuit
Haptic Driver
Fuel Gauge
Buttons
USB C Connector & ESD Protection
E-Paper Display Connector

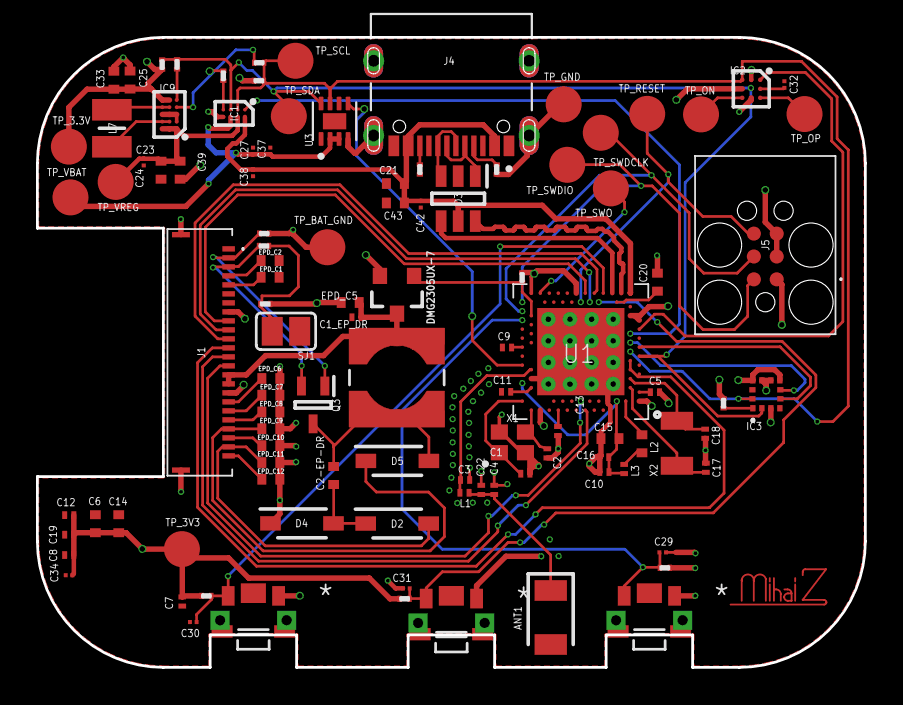
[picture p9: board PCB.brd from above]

Board: 4 copper layers, 46.0 x 35.0 mm, 105 parts (0 on the bottom side), 70 nets.

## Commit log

2026-04-10 Initial=Final Solution
    [PCB.brd, Schematic.sch]
2026-04-16 Add Schematic print-out
2026-04-17 Fix unrouted airwires for ANT1 and U1
    [PCB.brd]
2026-04-18 Add 3D models for components and update all impacted files - fix #3
    [PCB.brd]

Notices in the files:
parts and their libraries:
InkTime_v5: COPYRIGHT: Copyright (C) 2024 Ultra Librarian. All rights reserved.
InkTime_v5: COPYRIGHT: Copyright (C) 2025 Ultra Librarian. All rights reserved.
